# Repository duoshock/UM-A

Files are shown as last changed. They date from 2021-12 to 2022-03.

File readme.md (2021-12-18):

# **UM-A**

<a href="Assembly Guide/img/UMA_Mint_43.jpg">
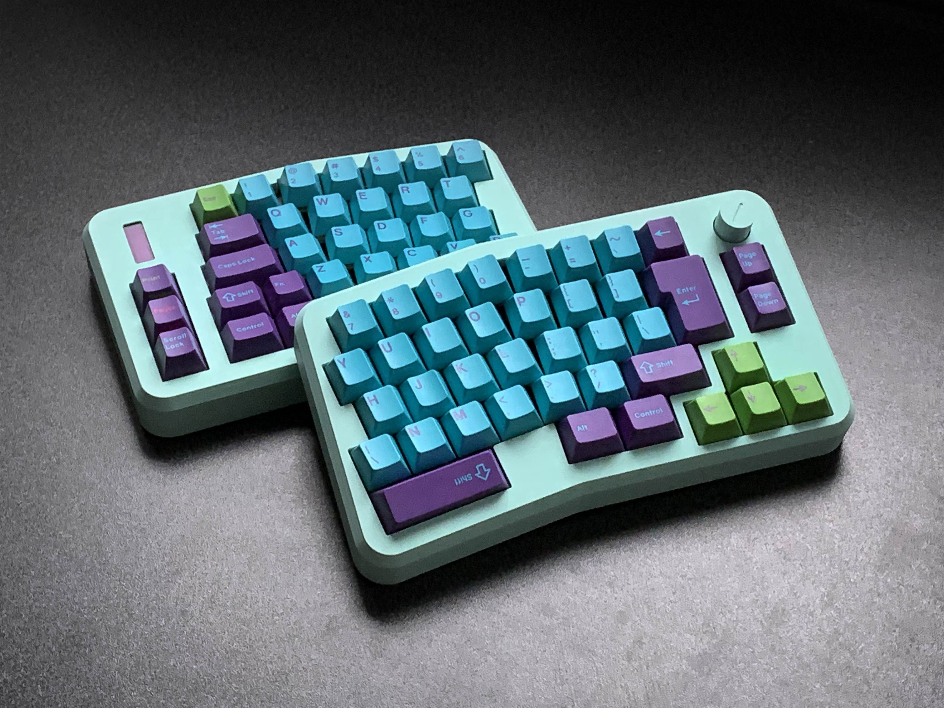
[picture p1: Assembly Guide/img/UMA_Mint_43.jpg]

</a>

**UM-A is an Alice style split keyboard with arrow cluster and macro keys along with encoder and OLED screen housed in 3D printed housings.**

Available on [Merge](https://mergedesign.store/)

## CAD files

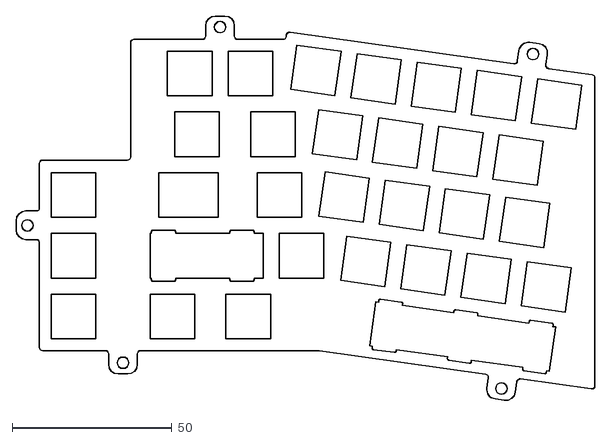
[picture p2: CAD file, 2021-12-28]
Print files/DXF/UM-A_L_Plate_v12.dxf
181.4 x 120.7

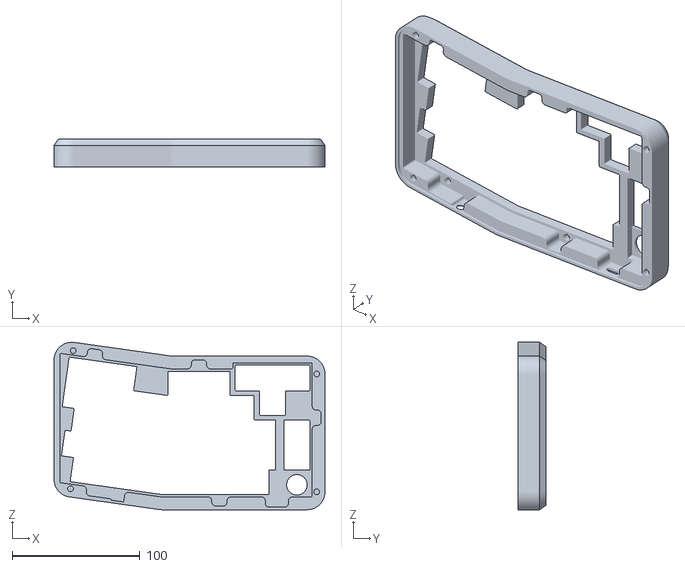
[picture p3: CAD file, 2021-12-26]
Print files/STL/UM-A_R_Top_v12_ISO.STL
212.0 x 22.0 x 131.0

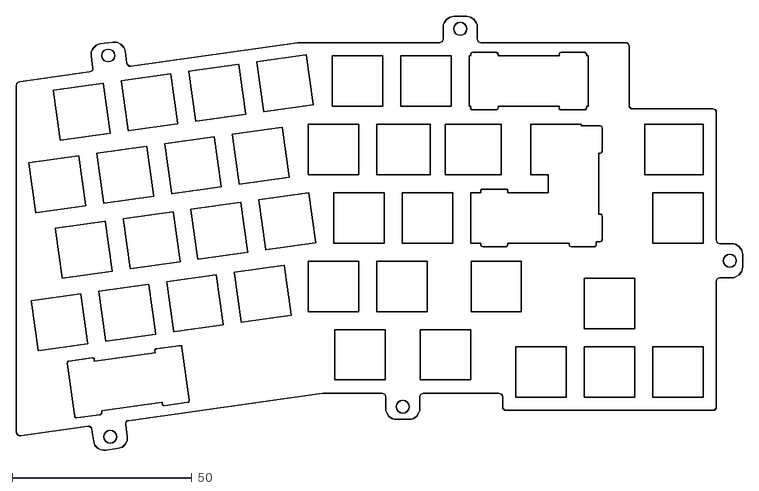
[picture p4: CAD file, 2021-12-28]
Print files/DXF/UM-A_R_Plate_v12.dxf
202.1 x 120.9

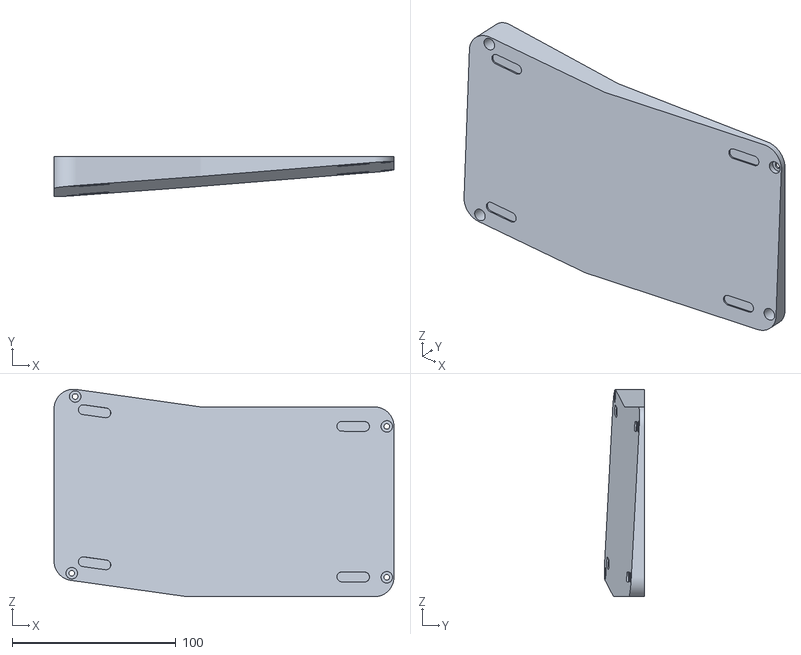
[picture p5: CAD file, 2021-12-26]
Print files/STL/UM-A_R_Cover_Tented_v12.STL
207.8 x 24.6 x 126.8

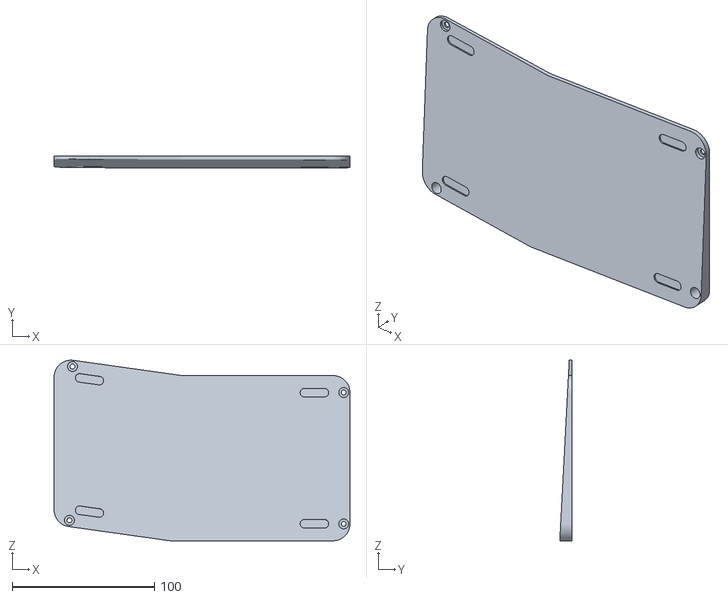
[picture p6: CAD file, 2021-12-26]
Print files/STL/UM-A_R_Cover_v12.STL
207.8 x 8.75 x 126.8

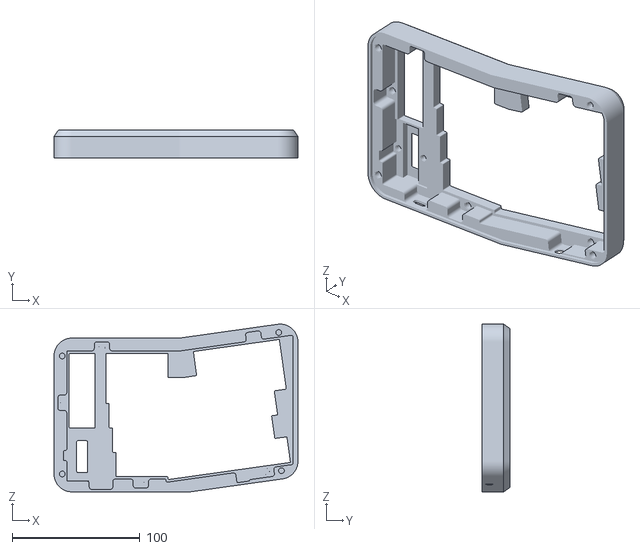
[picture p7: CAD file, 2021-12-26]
Print files/STL/UM-A_L_Top_v12.STL
190.7 x 22.0 x 131.1

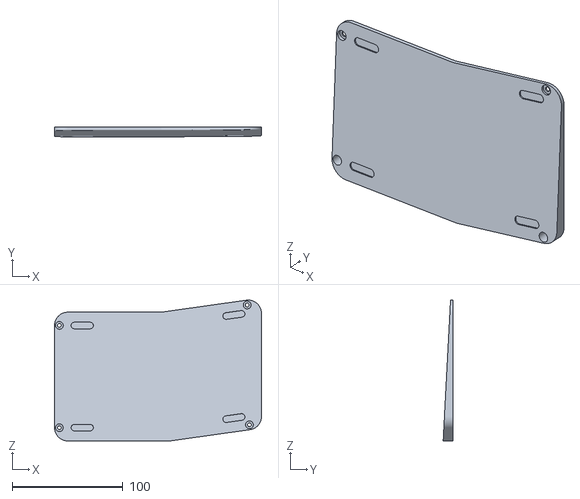
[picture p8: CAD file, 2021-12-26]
Print files/STL/UM-A_L_Cover_v12.STL
186.5 x 8.75 x 126.9

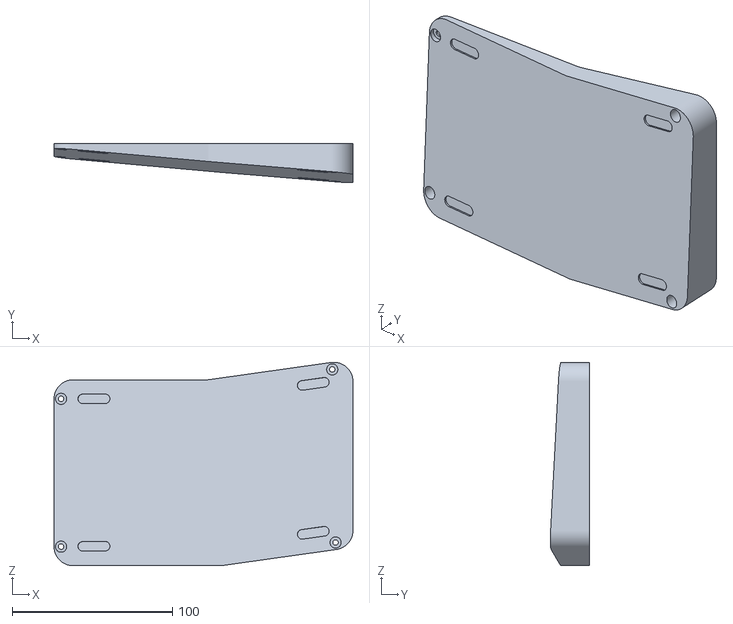
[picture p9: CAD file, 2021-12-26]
Print files/STL/UM-A_L_Cover_Tented_v12.STL
186.5 x 24.5 x 126.9

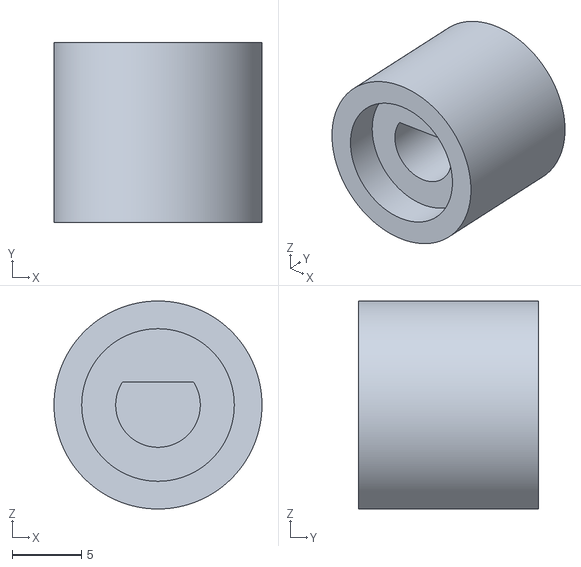
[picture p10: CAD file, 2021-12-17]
Print files/STL/UM-A_Knob_v1.STL
15.0 x 13.0 x 15.0

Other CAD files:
Print files/STL/UM-A_R_Top_v12_ANSI.STL

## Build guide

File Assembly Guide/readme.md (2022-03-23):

# UM-A Assembly Guide

## **Content of UM-A Kit**

<a href="img/UMA_Contents_2000px.jpg">
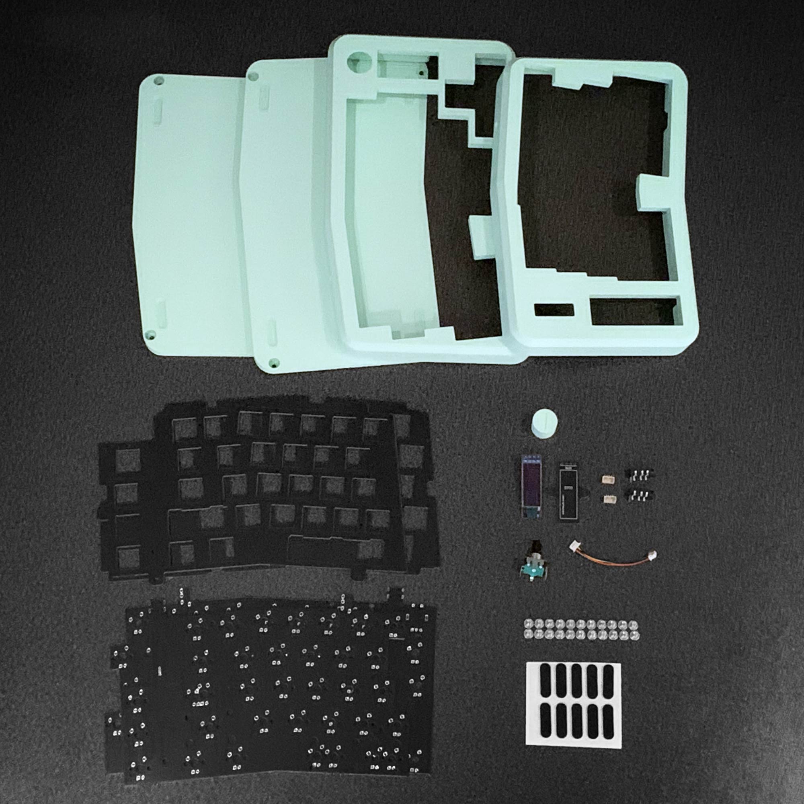
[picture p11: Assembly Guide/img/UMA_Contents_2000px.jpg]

</a>

**Housing** 
- 2 x Top Case
- 2 x Rear Cover
- 1 x Rotary Encoder Knob

**PCB**
- 1 x Left
- 1 x Right

**RF4 Plate**
- 1 x Left
- 1 x Right

**1 x OLED Screen PCB**

**1 x OLED Screen**

**2 x 4 Pins Sockets**

**1 x 4 Pins Cable**

**1 x Encoder**

**2 x TRRS PJ-320A**

**22 x M3 5mm screws** (Only 20 are required, rest are spare)

**8 x Rubber feet**

---

## **READ THIS FIRST / FAQ** ##

- *Why it disconnect when I plug in the TRRS cable?*

    TRRS cable carries data and power to the other half. When plugging the cable into the TRRS jack, the ring that carries power makes contact with the data pin and short the MCU. In most cases, the MCU will be fine after disconnecting the power, but something it can corrupts the EEPROM. In rare instance, kills the MCU. 

    **SO PLEASE DO NOT PLUG/UNPLUG TRRS CABLE WHEN POWER IS ON (I.E. WHEN USB CABLE IS CONNECTED).**

- *Why some keys are not registered on the right half when testing the PCB by connecting via USB cable?*

    The Left and right sides have a different key matrix (i.e. different number of keys). The pre-flashed firmware is set as master left, so when testing the right side via USB, the computer registers it as the left side which has less key than the right side.

    So it's normal to have some keys not registered on the right side when it is connected via USB. To perform a proper test, connect the right half via TRRS cable.

---

## **Test the PCBs before soldering**

<a href="img/UMA_Asm_TestPCB.jpg">
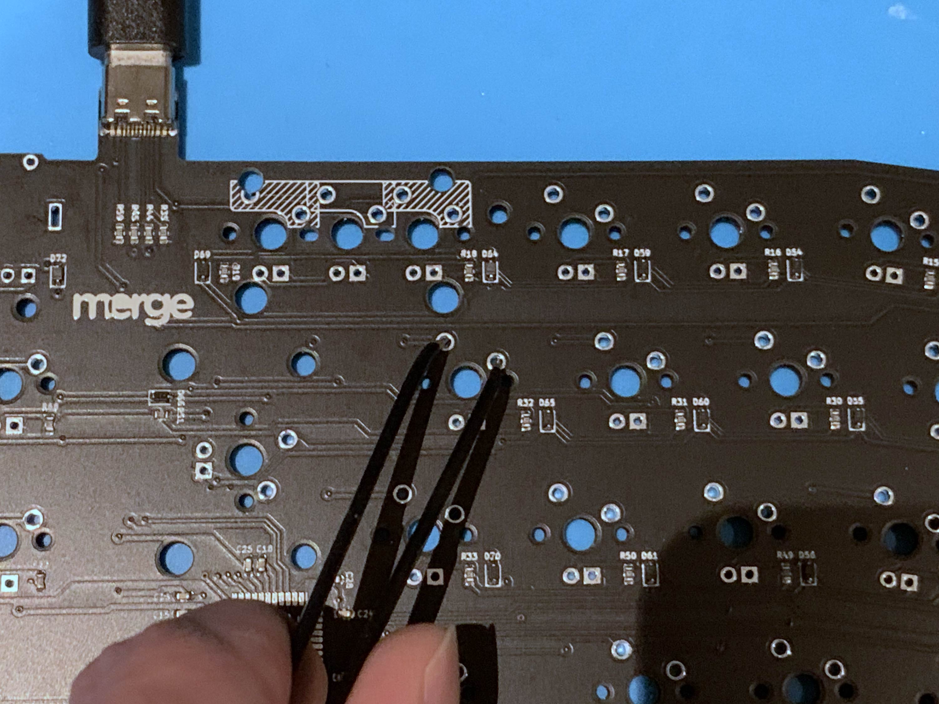
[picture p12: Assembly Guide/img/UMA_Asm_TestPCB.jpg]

</a>

All PCBs are tested prior shipping, but it is good practice to make sure they are working before soldering. Both PCBs come pre-flashed Vial firmware, it should be recognised in Vial when connected to a computer. Plug in one half and test by shorting switch pins with tweezers. After testing one half, disconnect the first and test the other half.

**Don’t panic if the right side PCB outputs the wrong key or somee keys not registering, as the firmware is set to left as master. As long as both halves produce some output you have verified the PCBs are working.**

---

## **Assembling the Main PCBs**

## OLED Screen Connector
<a href="img/UMA_Asm_OLEDConnector_A.jpg">
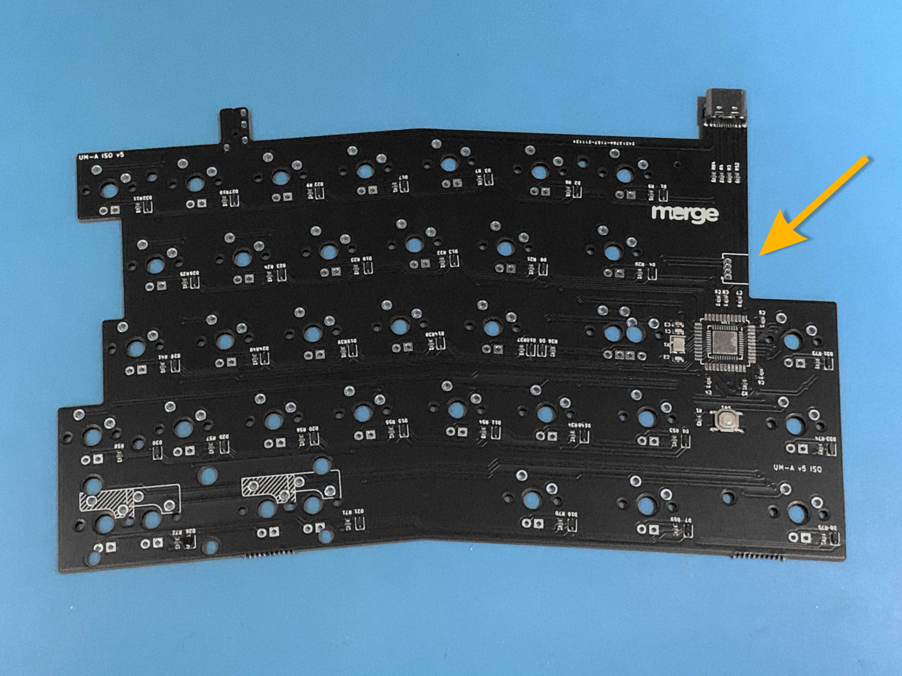
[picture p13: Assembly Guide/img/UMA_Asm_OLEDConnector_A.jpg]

</a>

OLED screen connector is located on the left half.

<a href="img/UMA_Asm_OLEDConnector_B.jpg">
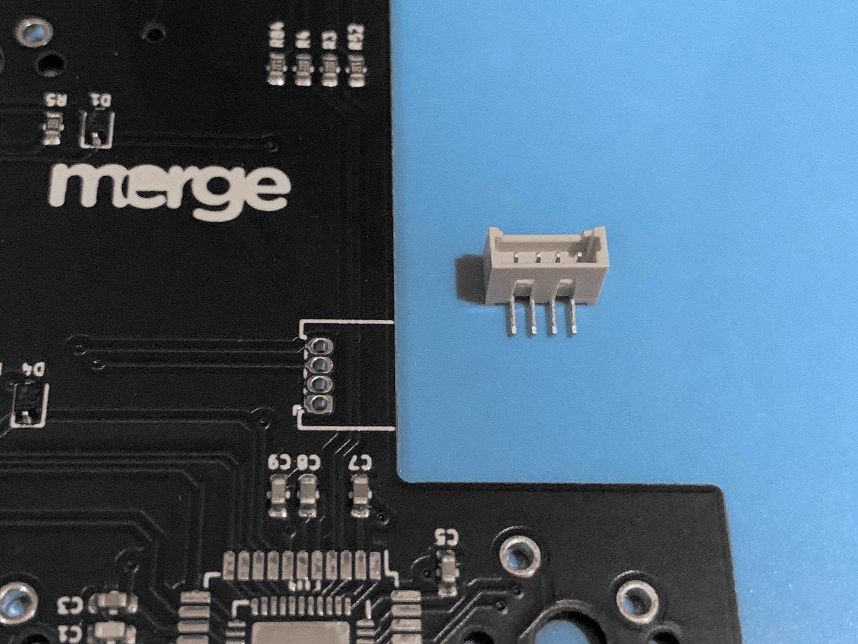
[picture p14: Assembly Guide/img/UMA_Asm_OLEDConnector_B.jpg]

</a>
<a href="img/UMA_Asm_OLEDConnector_C.jpg">
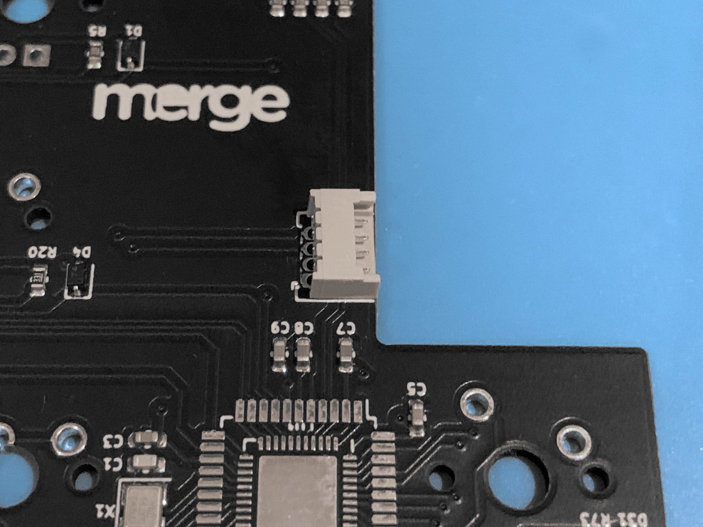
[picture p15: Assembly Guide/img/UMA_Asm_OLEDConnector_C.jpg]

</a>

Insert it on the underside of the PCB and then solder.

## TRRS Jacks
<a href="img/UMA_Asm_TRRS_A.jpg">
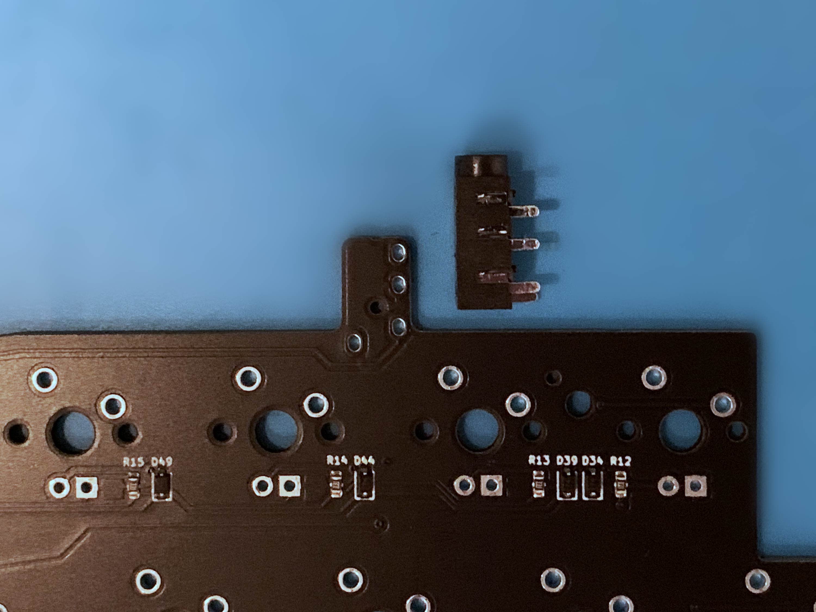
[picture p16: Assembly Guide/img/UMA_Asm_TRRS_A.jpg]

</a>
<a href="img/UMA_Asm_TRRS_B.jpg">
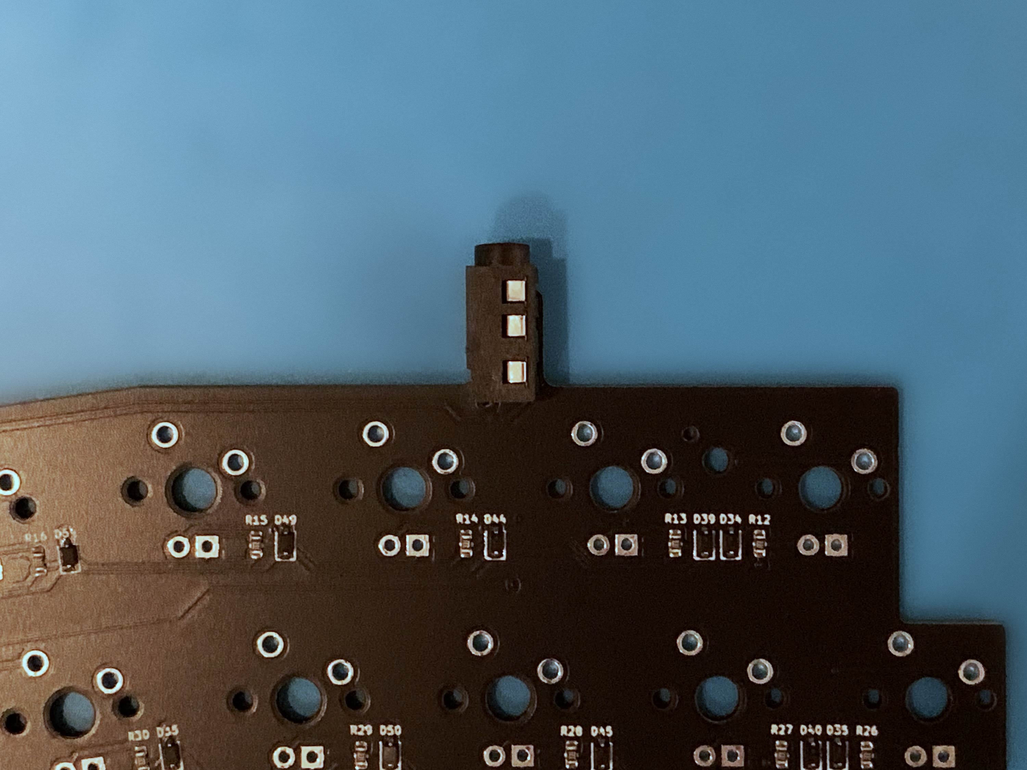
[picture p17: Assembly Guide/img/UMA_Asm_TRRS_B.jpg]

</a>

Place the jack on the underside of the PCB and solder.

>**DO NOT PLUG/UNPLUG TRRS CABLE WHEN POWER IS ON (I.E. WHEN USB CABLE IS CONNECTED), IT CAN SHORT THE CONTROLLER.**

## Encoder
<a href="img/UMA_Asm_Encoder_A.jpg">
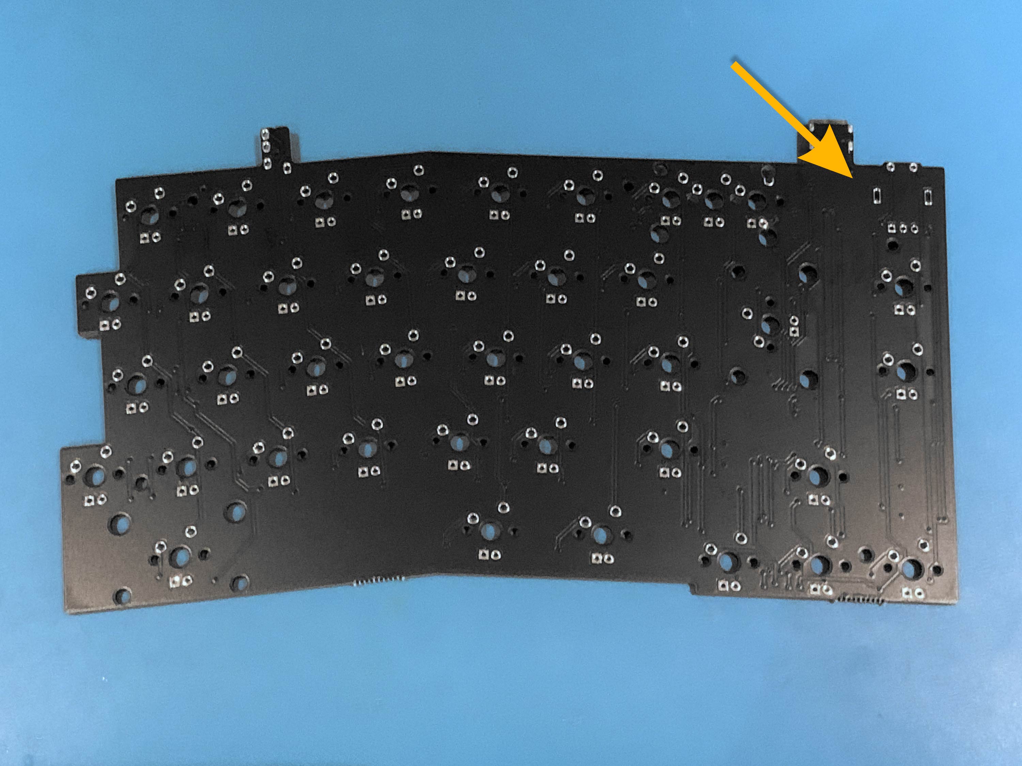
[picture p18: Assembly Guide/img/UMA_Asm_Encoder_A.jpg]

</a>

Encoder is located on the right half.

<a href="img/UMA_Asm_Encoder_B.jpg">
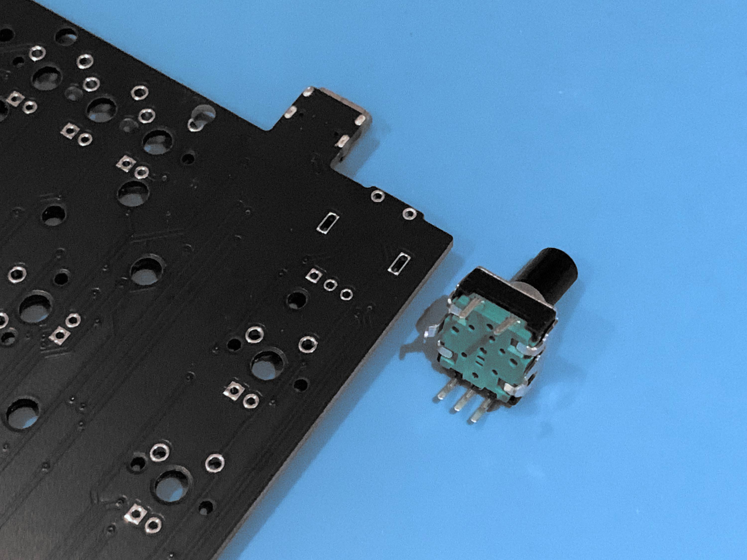
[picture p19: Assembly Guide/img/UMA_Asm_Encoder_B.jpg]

</a>
<a href="img/UMA_Asm_Encoder_C.jpg">
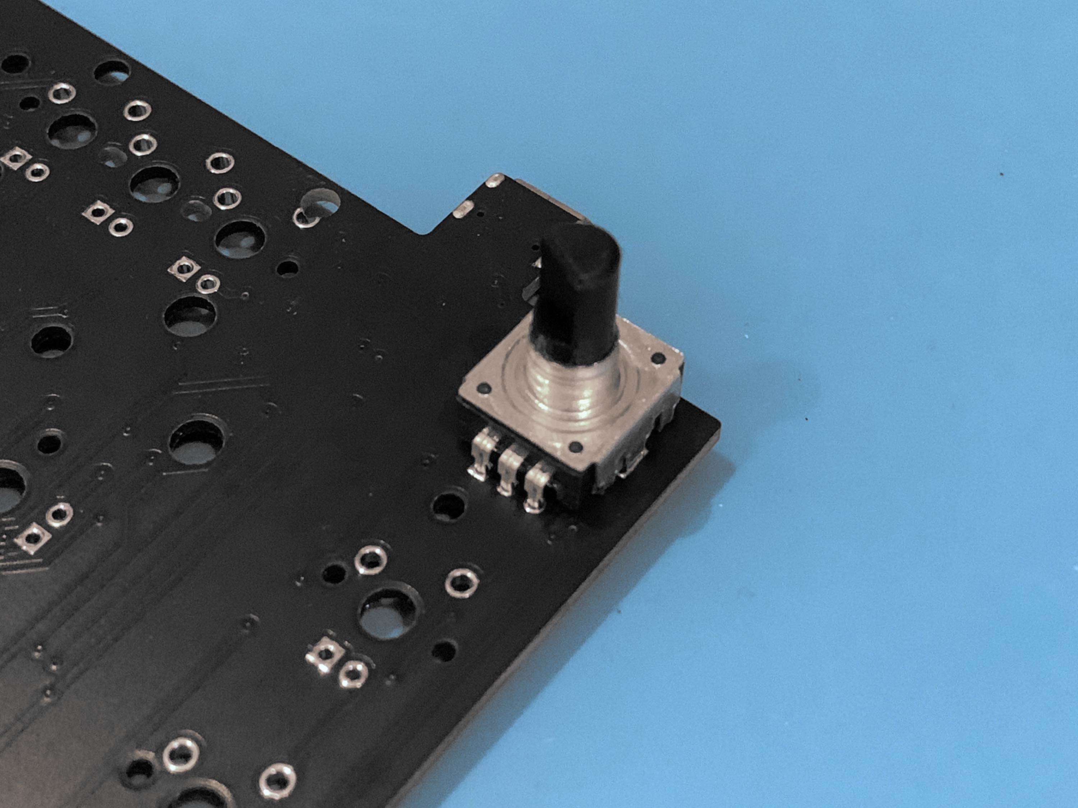
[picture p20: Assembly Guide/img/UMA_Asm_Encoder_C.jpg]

</a>

Insert encoder to the front of the PCB, solder it from the underside of the PCB.

## Stabilisers

<a href="img/UMA_Asm_Stab_A.jpg">
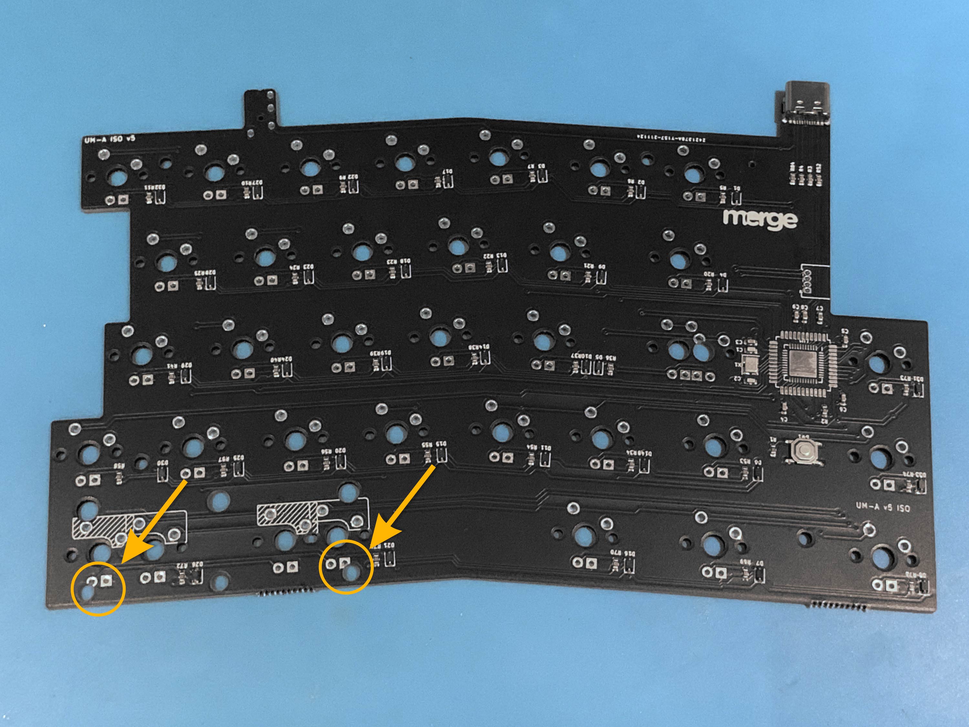
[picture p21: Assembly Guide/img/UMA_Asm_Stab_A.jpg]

</a>
<br>
<a href="img/UMA_Asm_Stab_B.jpg">
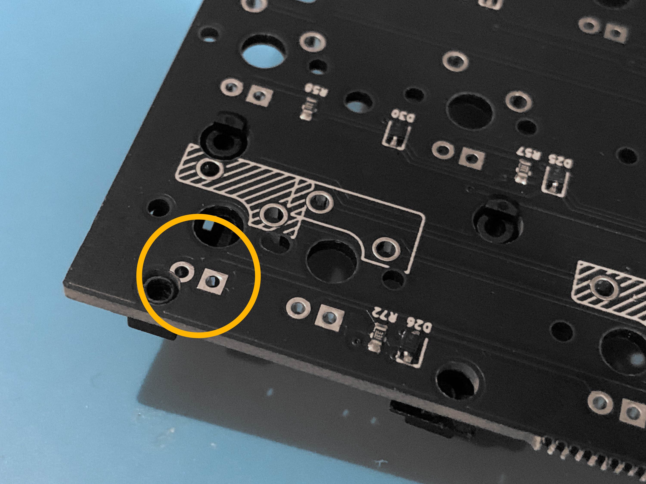
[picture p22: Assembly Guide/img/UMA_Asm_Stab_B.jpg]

</a>
<a href="img/UMA_Asm_Stab_C.jpg">
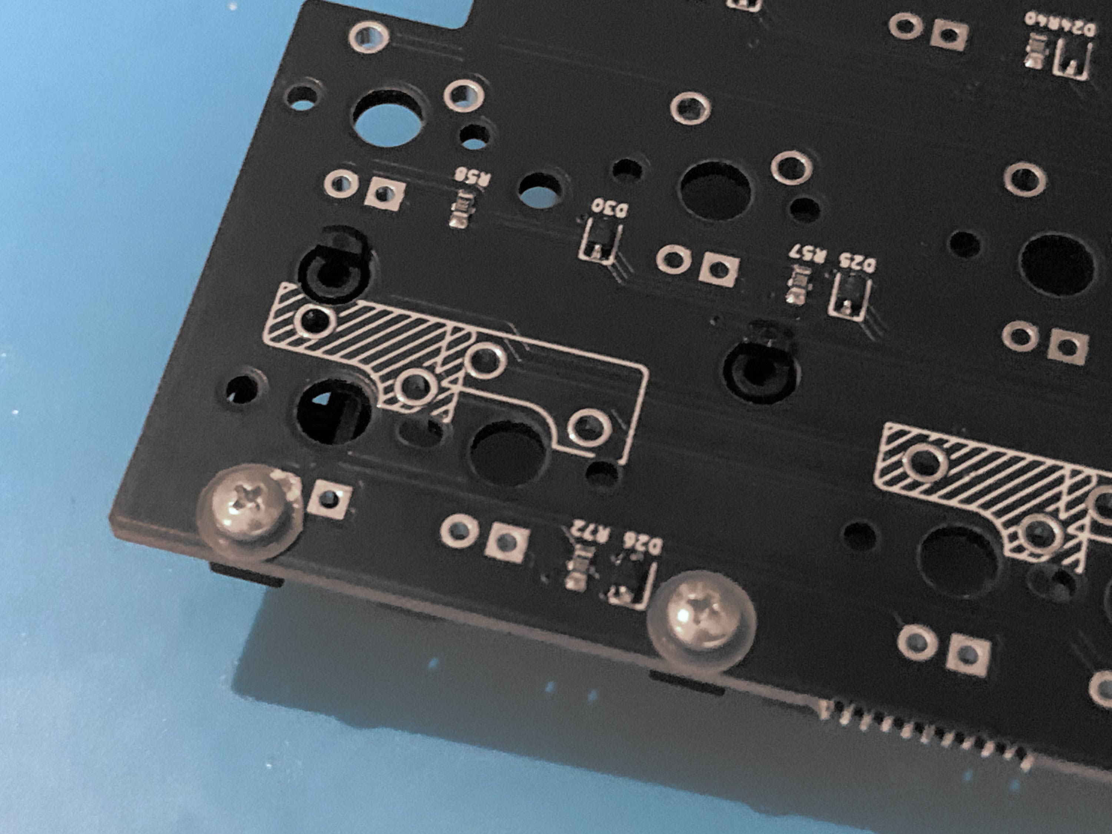
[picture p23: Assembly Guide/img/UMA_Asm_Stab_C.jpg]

</a>

When installing screw-in stabiliser for Spacekey on the left half, use a washer/electrical tape to isolate the screw and the LED contacts to prevent shorting.

## Select PCB Layout before solding switches
<a href="img/UMA_Asm_Layout_L.jpg">
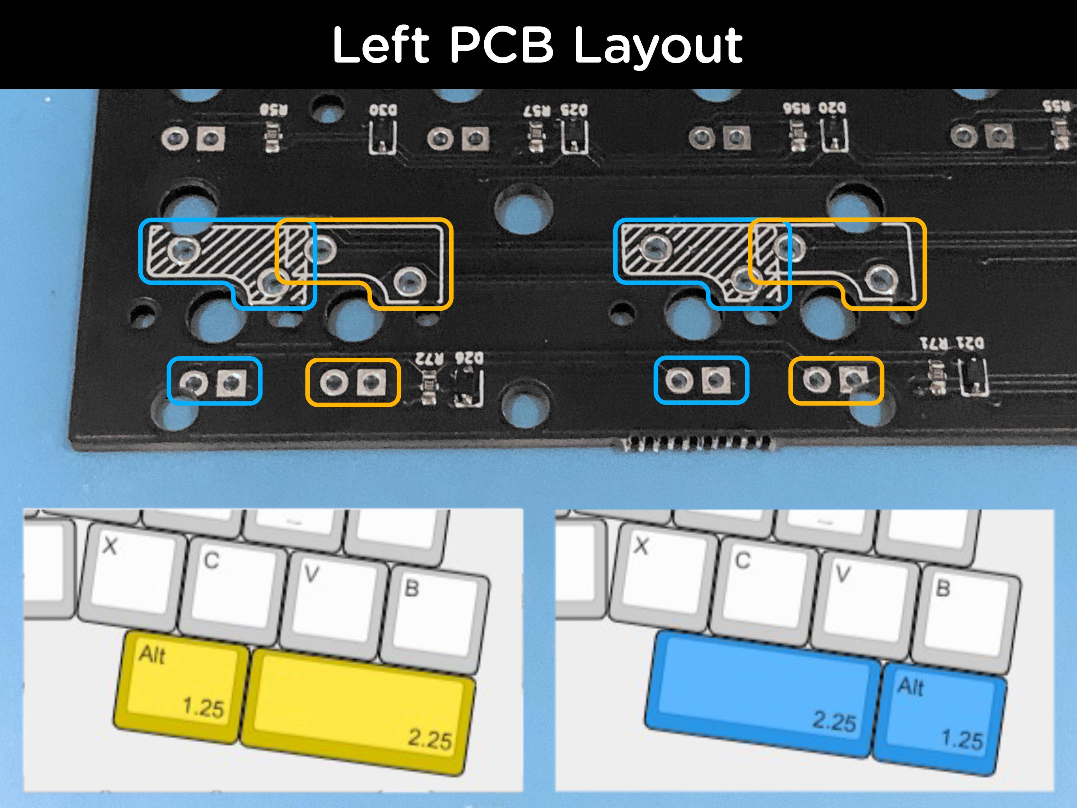
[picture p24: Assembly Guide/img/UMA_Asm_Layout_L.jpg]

</a>

<a href="img/UMA_Asm_Layout_R.jpg">
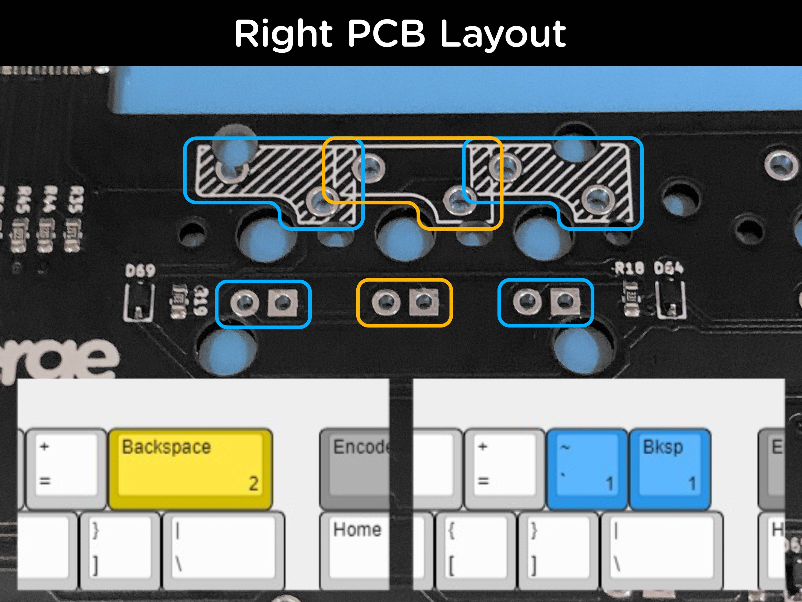
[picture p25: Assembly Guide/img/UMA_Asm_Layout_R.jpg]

</a>

Select one layout when soldering switches. Then insert switches to the plates and solder to the PCBs.

## Soldering switches

Soldering switches (http://www.youtube.com/watch?v=JpV-eJNrXjk "How To Build Your Own Mechanical Keyboard! (With an EASY Soldering Tutorial!)")

Solder switches as you normally would with other keyboards.
Here is a good tutorial by JUJU.

## LED
<a href="img/UMA_Asm_LED.jpg">
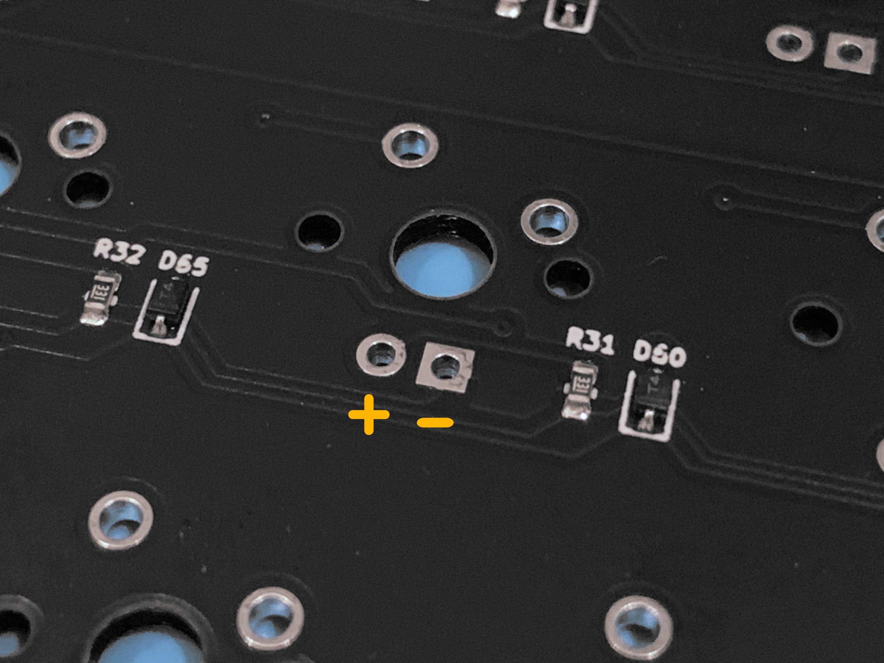
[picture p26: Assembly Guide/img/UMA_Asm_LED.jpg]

</a>

Round pad: Anode (+)

Square pad: Cathode (-)

---

## **Soldering OLED screen PCB**

<a href="img/15_OLED_PCB.jpg">
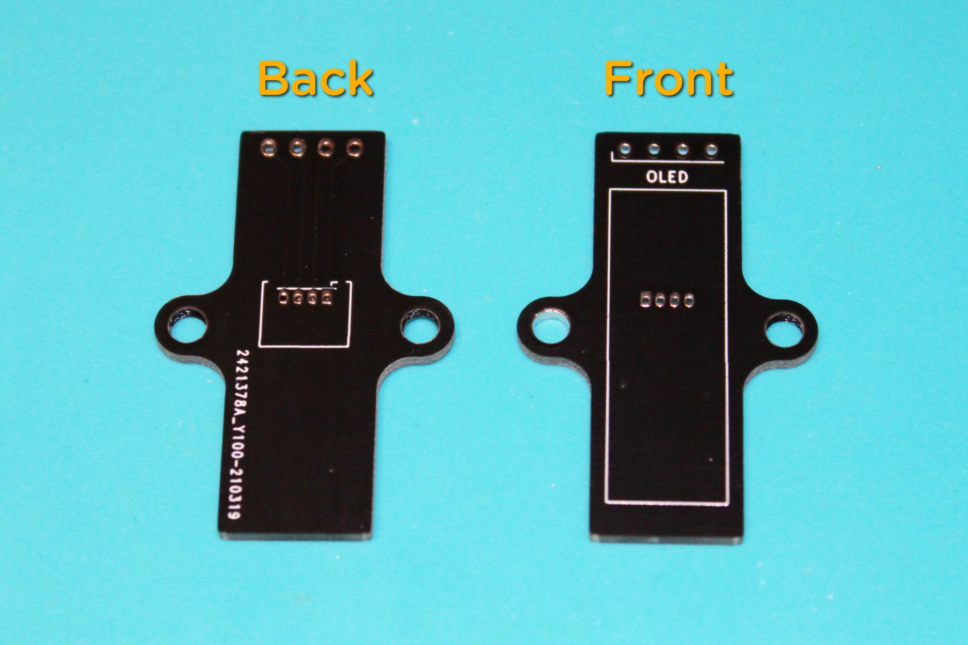
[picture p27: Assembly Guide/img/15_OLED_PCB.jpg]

</a>

Note the front and back of the PCB

<a href="img/16_OLED_Conn_A.jpg">
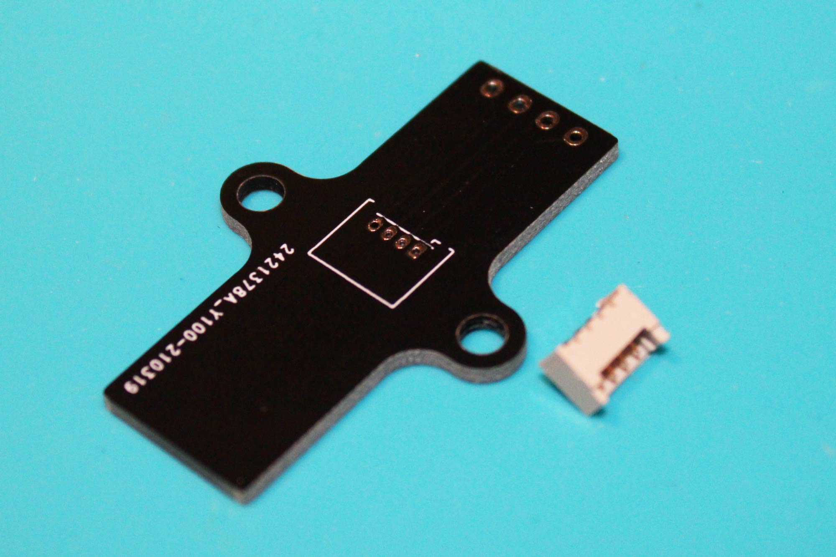
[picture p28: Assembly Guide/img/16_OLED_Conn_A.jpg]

</a>
<a href="img/16_OLED_Conn_B.jpg">
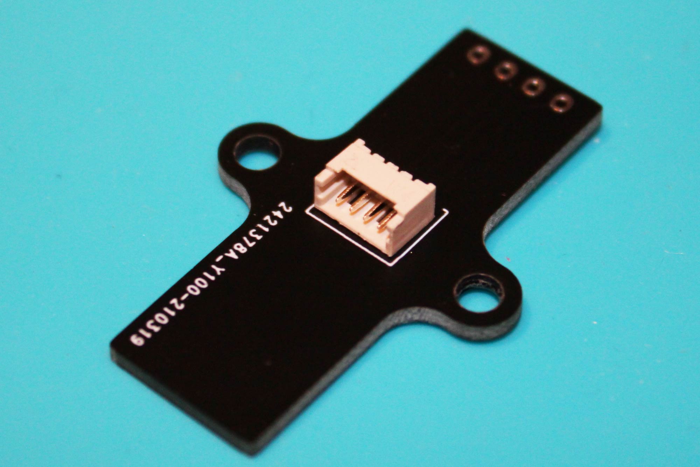
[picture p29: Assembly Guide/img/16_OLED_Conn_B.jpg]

</a>

Insert the 4 pin connector to the back of the PCB. Align it with the marking on the PCB and then solder each pin from the front.

### **Be sure to solder correctly in this step, as there will be no access to the solder joints once the OLED screen is in place.**

<a href="img/OLEDScreen_A.jpg">
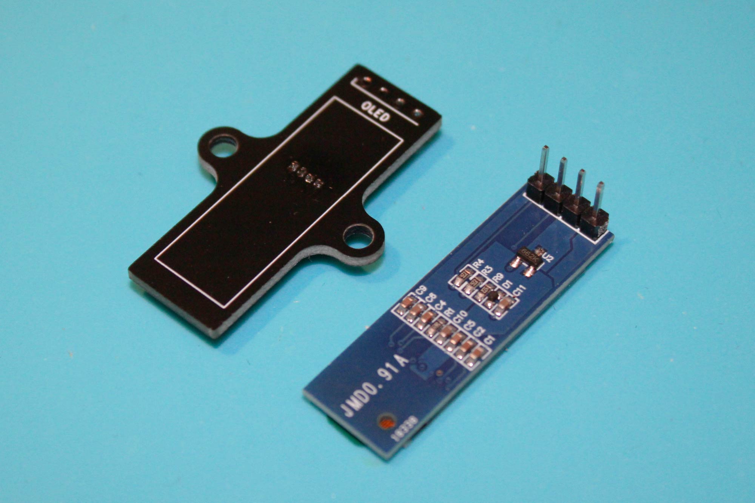
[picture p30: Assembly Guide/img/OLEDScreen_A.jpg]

</a>
<a href="img/OLEDScreen_B.jpg">
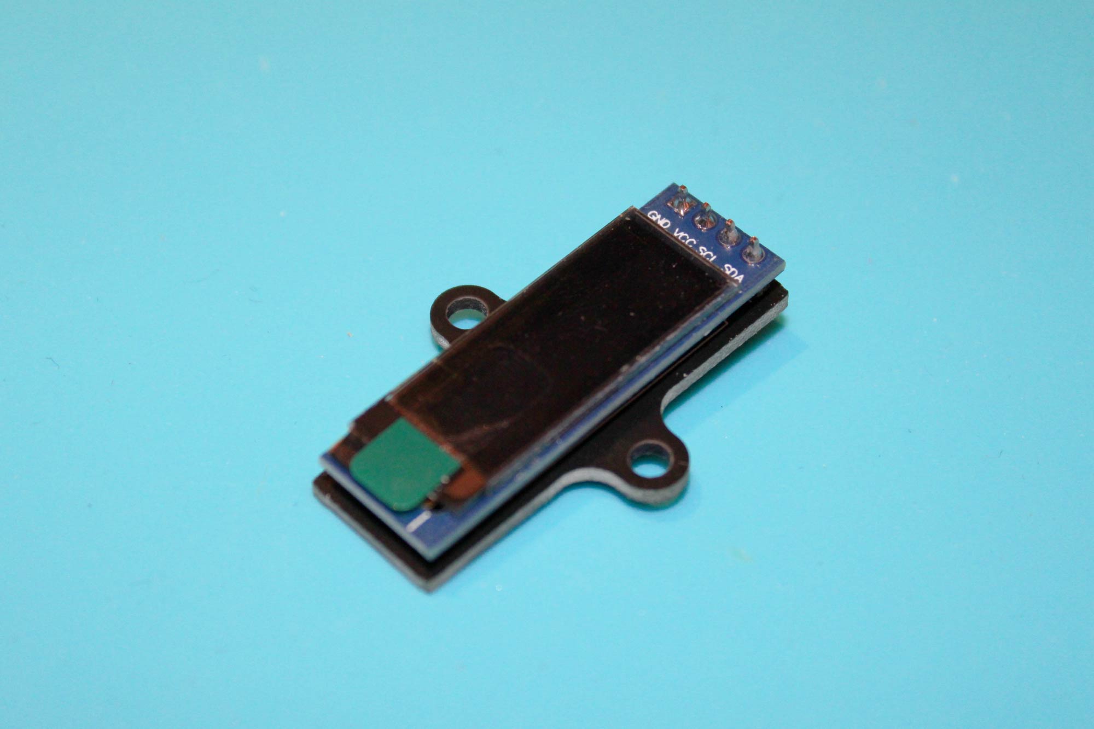
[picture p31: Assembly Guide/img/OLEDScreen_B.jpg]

</a>

Insert the short pins of the OLED screen header through the back of the OLED PCB then solder from the front. Then place the long pins of the screen header through the black mounting PCB and solder each pin from the underside.

<a href="img/17_OLED_Trim_A.jpg">
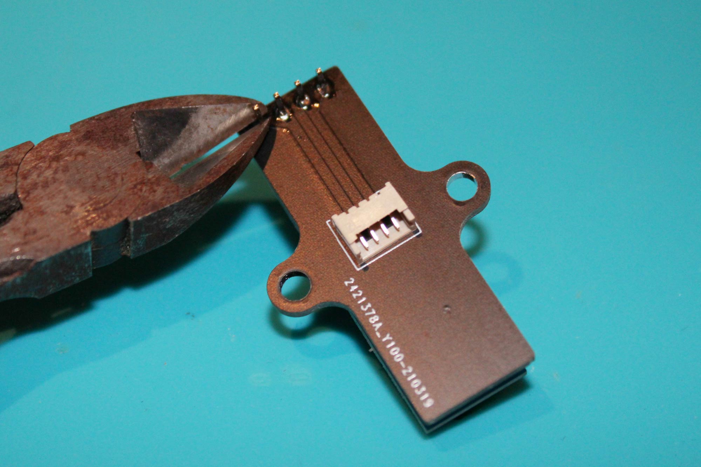
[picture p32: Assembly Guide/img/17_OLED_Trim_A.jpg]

</a>
<a href="img/17_OLED_Trim_B.jpg">
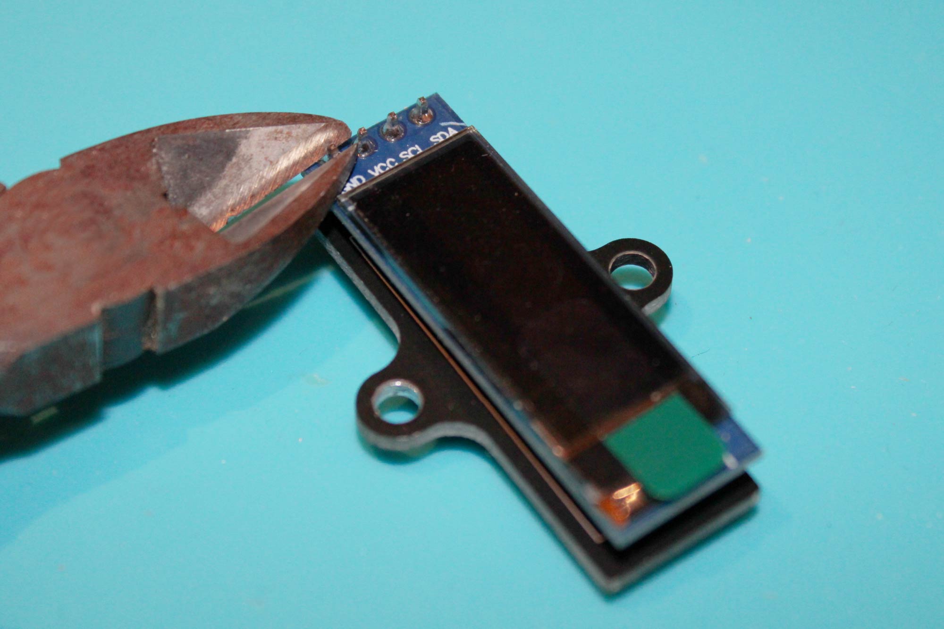
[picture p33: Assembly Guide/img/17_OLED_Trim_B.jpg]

</a>

Trim header pins short on both side. 

<a href="img/17_OLED_Trim_C.jpg">
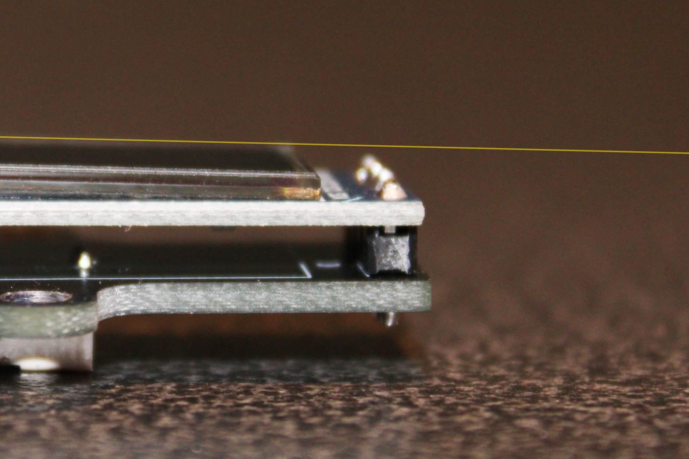
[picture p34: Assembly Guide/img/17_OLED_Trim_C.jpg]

</a>
<a href="img/OLED_Tilt.jpg">
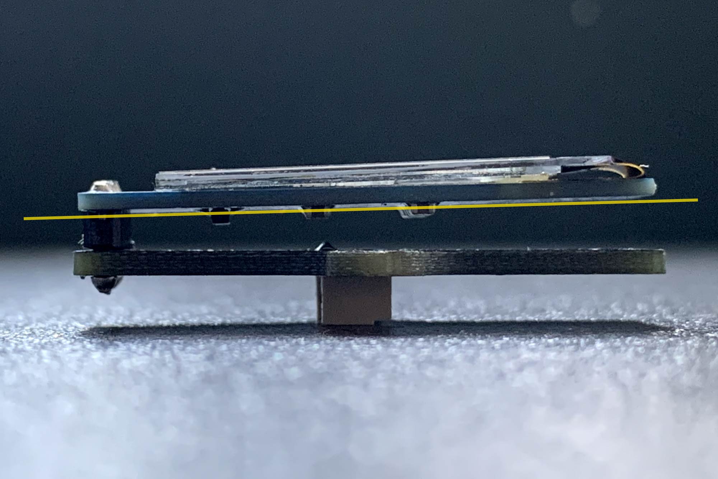
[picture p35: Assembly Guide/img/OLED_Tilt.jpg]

</a>

Be sure the pins on the front are not protruding higher than the screen. Also, tilt-up the OLED screen slightly. Otherwise, there will be a gap between the case and the screen.

<a href="img/UMA_Asm_OLEDInstall_A.jpg">
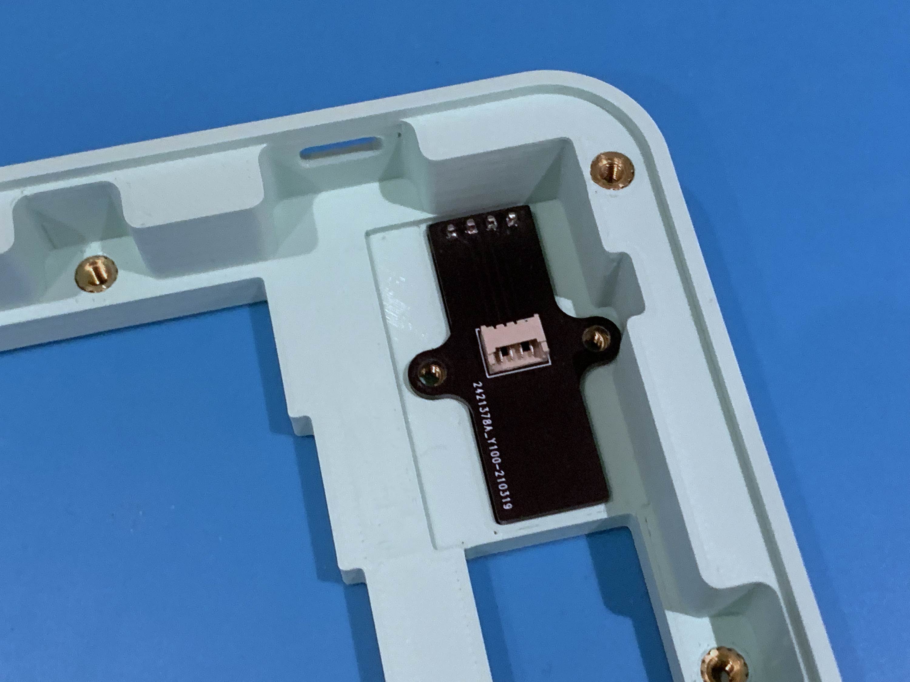
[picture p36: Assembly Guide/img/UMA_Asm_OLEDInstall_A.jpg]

</a>
<a href="img/UMA_Asm_OLEDInstall_B.jpg">
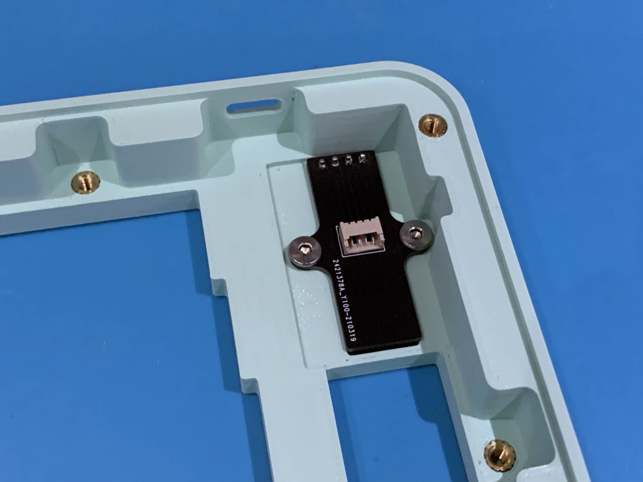
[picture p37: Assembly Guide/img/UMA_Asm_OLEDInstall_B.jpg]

</a>

Attached the OLED screen to the left case with 2 M3 5mm screws.

## **Mount PCB assembly to case**

<a href="img/UMA_Asm_CaseInstall_A.jpg">
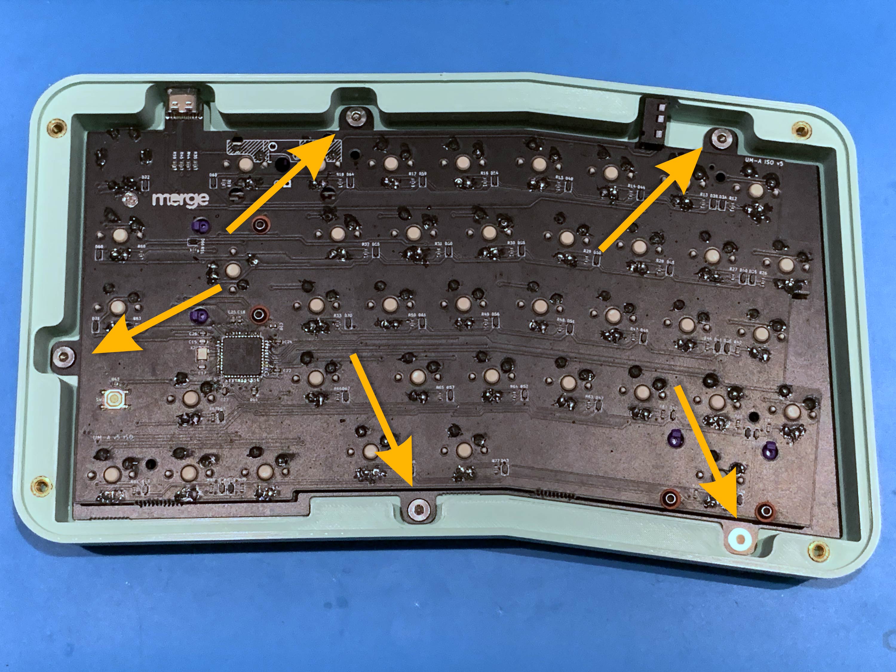
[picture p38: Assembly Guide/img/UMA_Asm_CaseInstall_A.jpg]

</a>
<a href="img/UMA_Asm_CaseInstall_B.jpg">
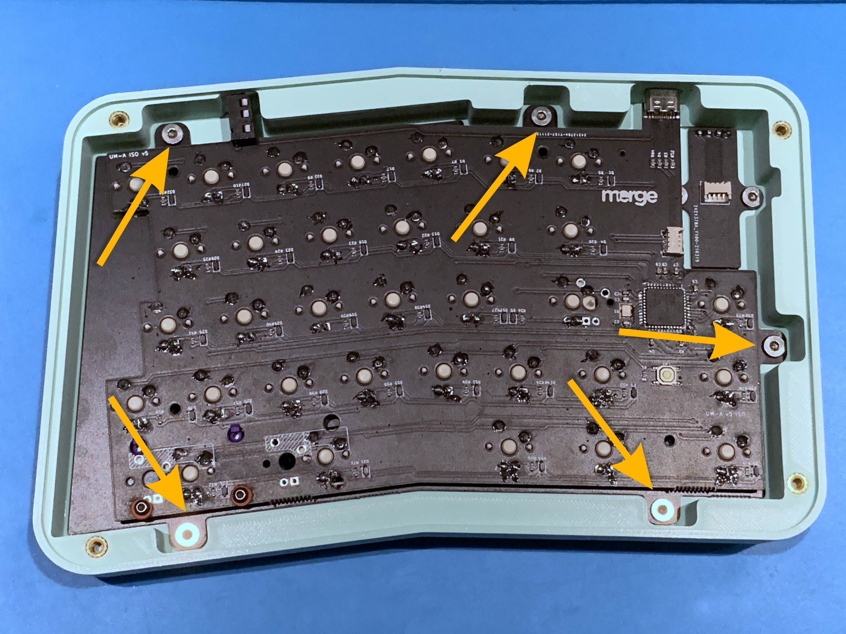
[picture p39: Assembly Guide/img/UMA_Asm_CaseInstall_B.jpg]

</a>

There are 5 mounting points on each side. Secure the PCB with the M3 5mm screws.

## **Connecting OLED screen**

<a href="img/UMA_Asm_OLEDCable.jpg">
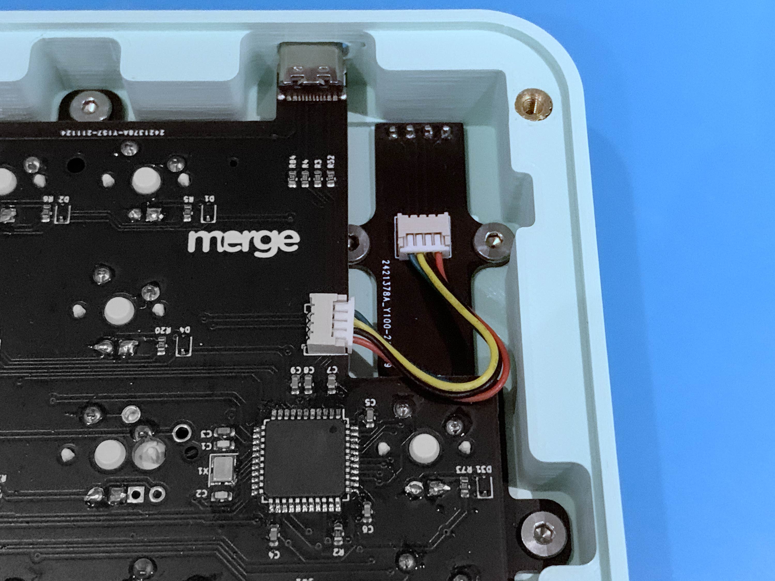
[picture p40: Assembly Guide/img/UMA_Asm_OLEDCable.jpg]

</a>

Connect OLED screen with the 4 pin cable.

## **Case Assembly**

<a href="img/UMA_Asm_Cover.jpg">
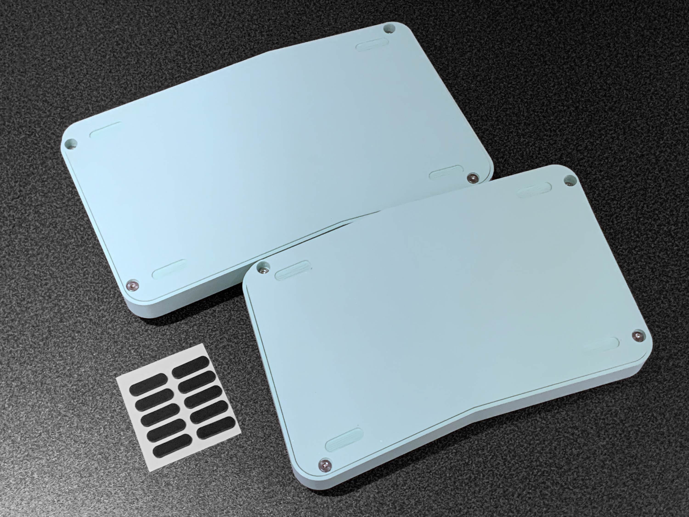
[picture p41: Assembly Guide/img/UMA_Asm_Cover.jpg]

</a>

Place the cover onto the case, fasten them with M3 5mm screws. Stick the rubber feet on and it’s done!

---

<a href="img/UMA_Mint_43.jpg">

</a>

---

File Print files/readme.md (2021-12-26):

# **Print guide**

## **Print files**

There are 5 parts need to be printed in order to complete the build.
- Left case (UM-A_L_Top_v12.STL)
- Left cover / tented cover (UM-A_L_Cover_v12.STL / UM-A_L_Cover_Tented_v12.STL)
- Right case ANSI / ISO (UM-A_R_Top_v12_ANSI.STL / UM-A_R_Top_v12_ISO.STL)
- Right cover / tented cover (UM-A_L_Cover_v12.STL / UM-A_R_Cover_Tented_v12.STL)
- Knob (UM-A_Knob_v1.STL)

## **Recommended print setting**
<a href="img/UMA_Print_Ori_A.jpg">
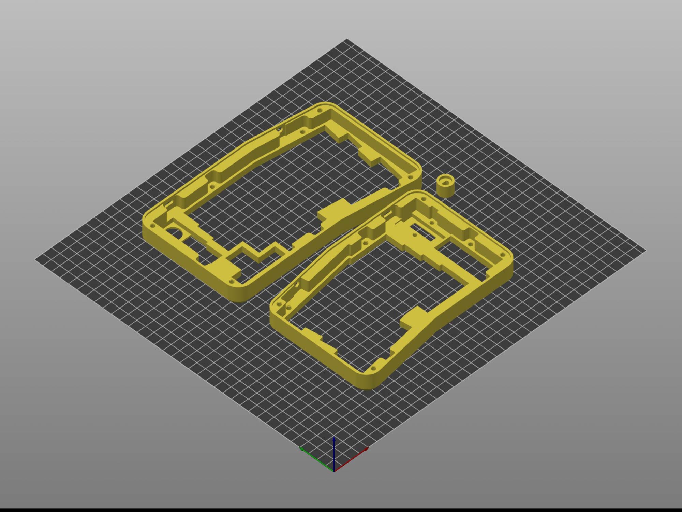
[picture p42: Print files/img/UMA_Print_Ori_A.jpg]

</a>
<a href="img/UMA_Print_Ori_B.jpg">
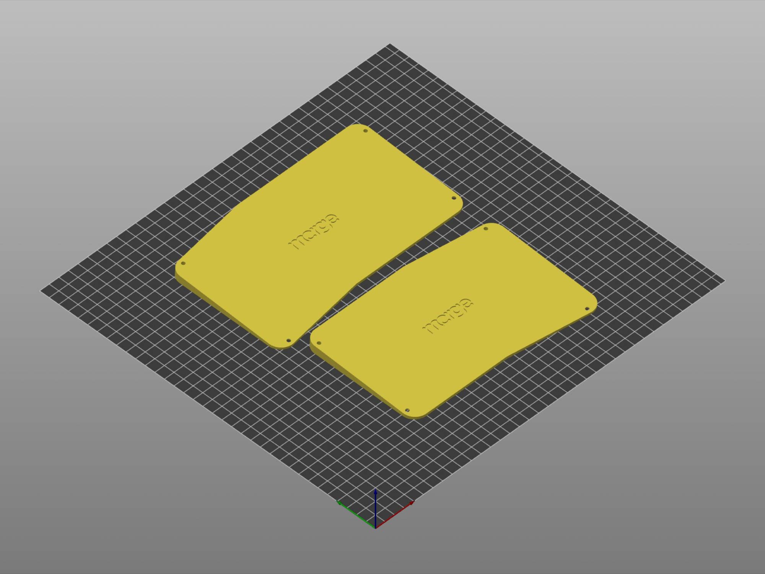
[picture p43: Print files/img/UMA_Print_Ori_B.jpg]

</a>
<a href="img/UMA_Print_Ori_C.jpg">
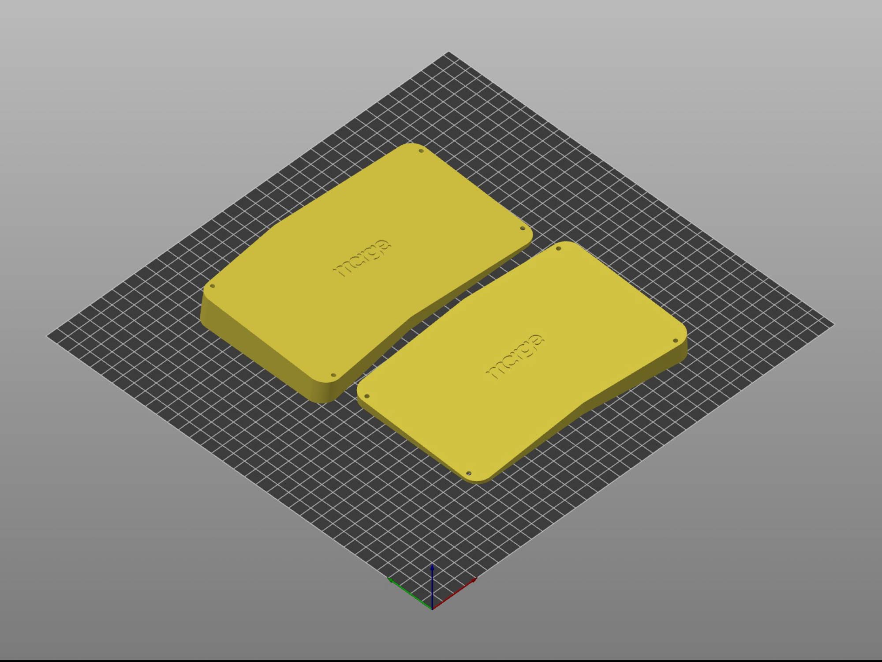
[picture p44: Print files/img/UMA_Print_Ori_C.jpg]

</a>

- 0.4mm Nozzle
- 0.2mm layer height
- ≥ 15% infill

All parts are designed to be printed with 0.4 nozzle at 0.2mm layer height without support, see print orientation.

## **Thread Inserts**
<a href="img/UMA_Print_Left.jpg">
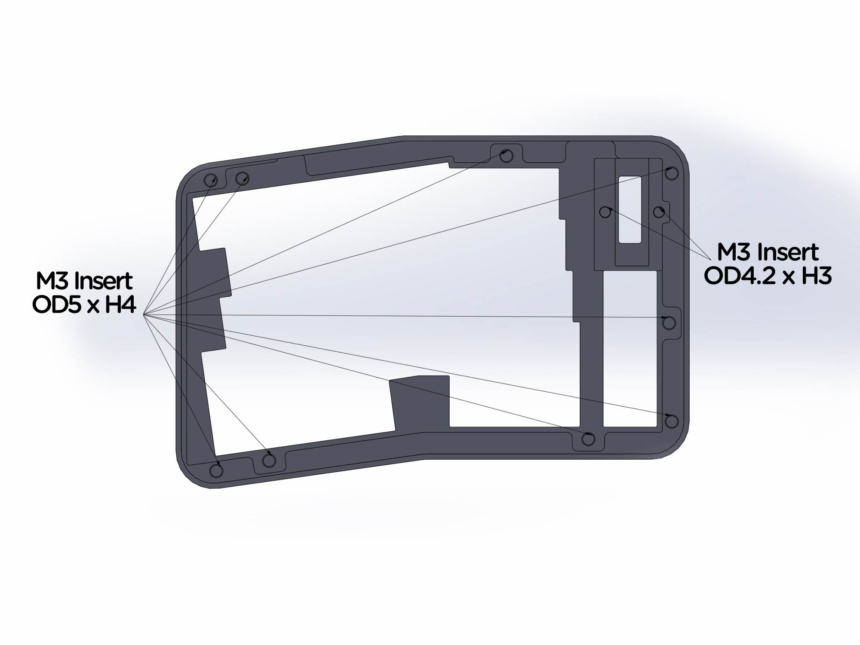
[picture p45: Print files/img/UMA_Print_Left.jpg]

</a>
<a href="img/UMA_Print_Right.jpg">
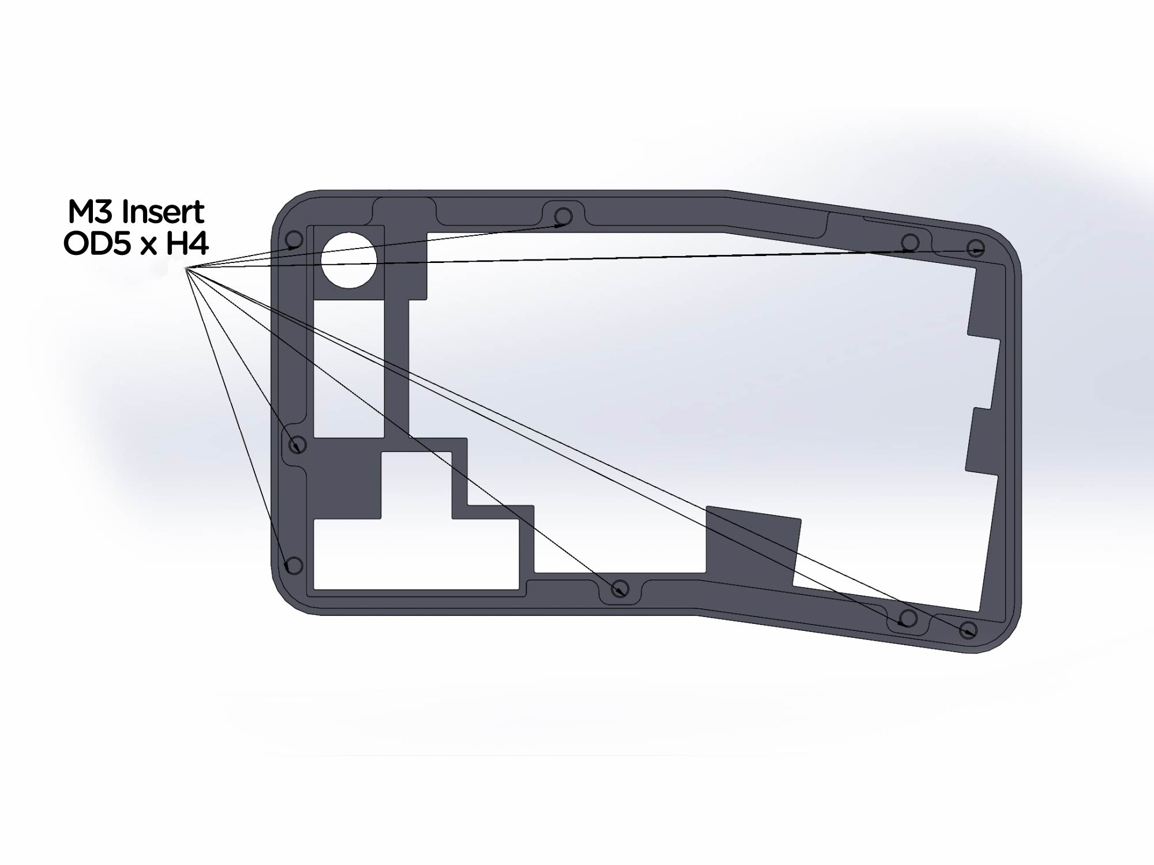
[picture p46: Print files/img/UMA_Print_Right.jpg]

</a>

PCB kit comes with heat-set threaded inserts for both halves. All mount holes are designed to accept M3 OD5 x H5 except OLED mounts which is OD4.2 x H3. See above for details.
